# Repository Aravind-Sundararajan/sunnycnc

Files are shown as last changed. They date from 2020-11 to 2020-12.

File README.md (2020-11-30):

# sunnycnc
I was making my own cnc that runs off circuitpython or pycnc and ROS so I thought I should put the files up here. 

I will update the bom as time goes on, but in the current iteration:

**relevant BOM**
* proxxon micromot 50
* raspberry pi3 b+ -I am not sure if I can do octoprint for CNC but I can try
* arduino mega 2560
* RAMPS shield
* 4 NEMA-17 stepper motors

**Power Delivery**
* 12V rail for the micromot (you do NOT need to buy their proprietary power supply) and for nema 17 steppers on the RAMPS 

some modification to mainline marlin tbd or a python script converter that transforms Grbl to reprap 

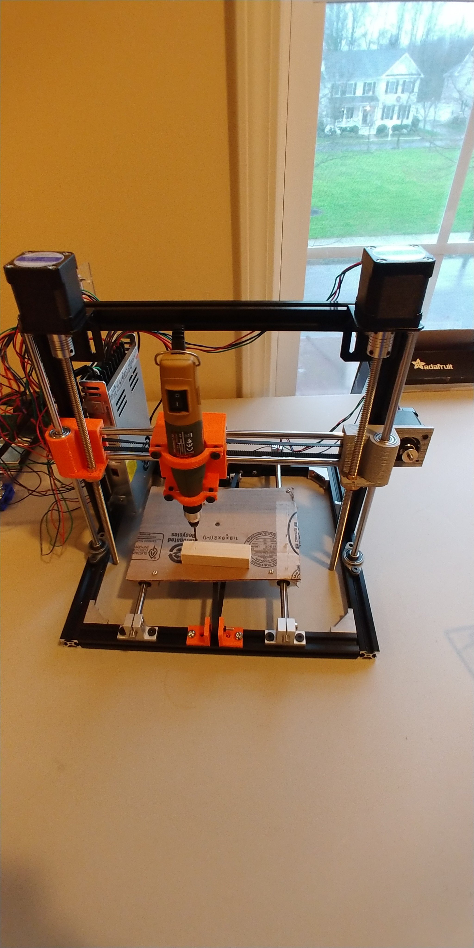
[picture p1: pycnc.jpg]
simple


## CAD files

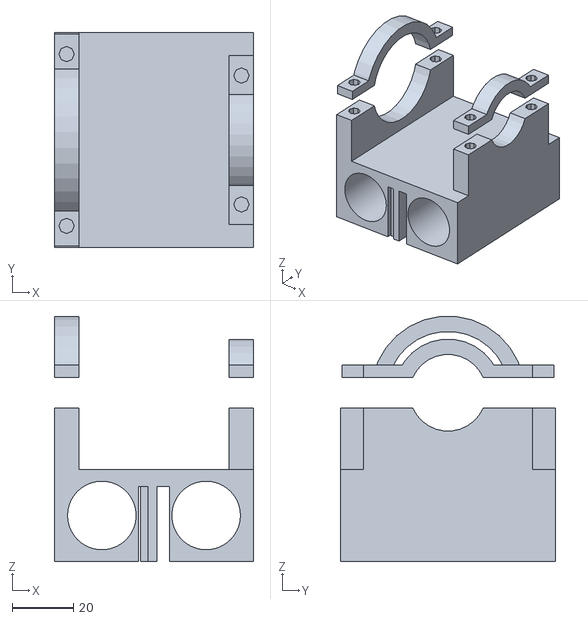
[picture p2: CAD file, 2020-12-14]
stls_and_scad/cnc_holder.stl
65.0 x 70.0 x 79.9

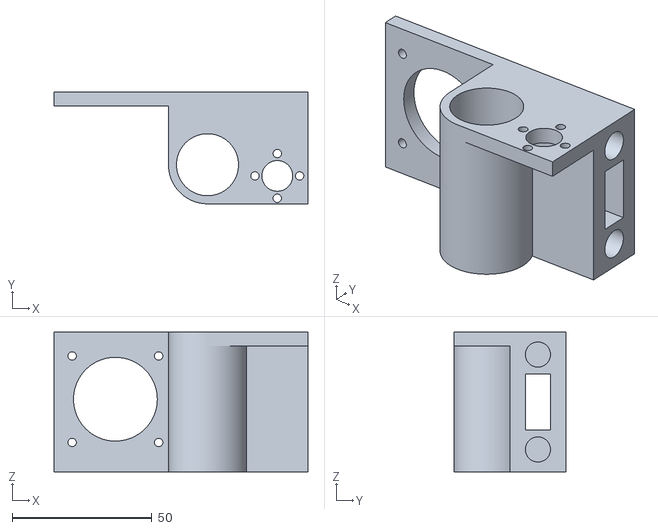
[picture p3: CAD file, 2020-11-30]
stls_and_scad/3d_printer_x_axis_right.stl
91.0 x 40.0 x 50.0

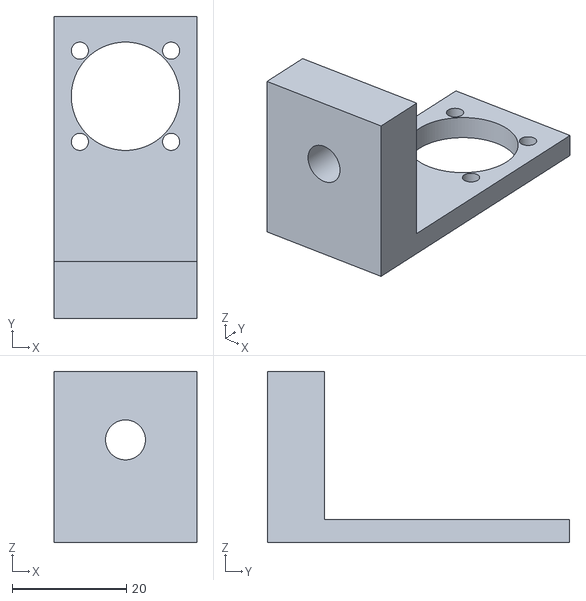
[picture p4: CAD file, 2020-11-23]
stls_and_scad/nema8_holder.stl
25.0 x 53.0 x 30.0

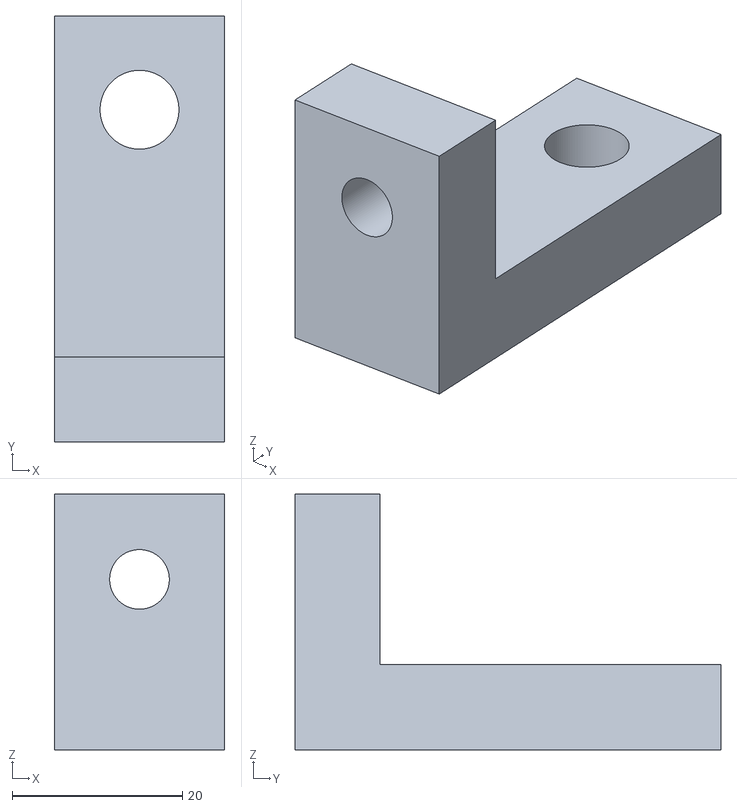
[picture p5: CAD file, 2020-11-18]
stls_and_scad/bar_holder.stl
20.0 x 50.0 x 30.0

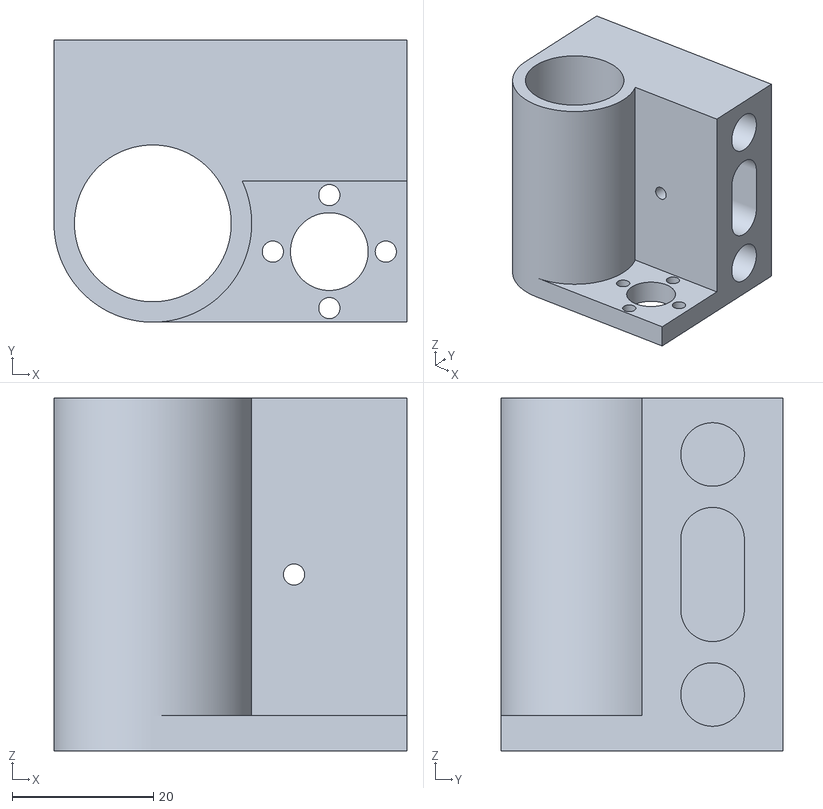
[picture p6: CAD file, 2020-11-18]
stls_and_scad/3d_printer_x_axis_left.stl
50.0 x 40.0 x 50.0

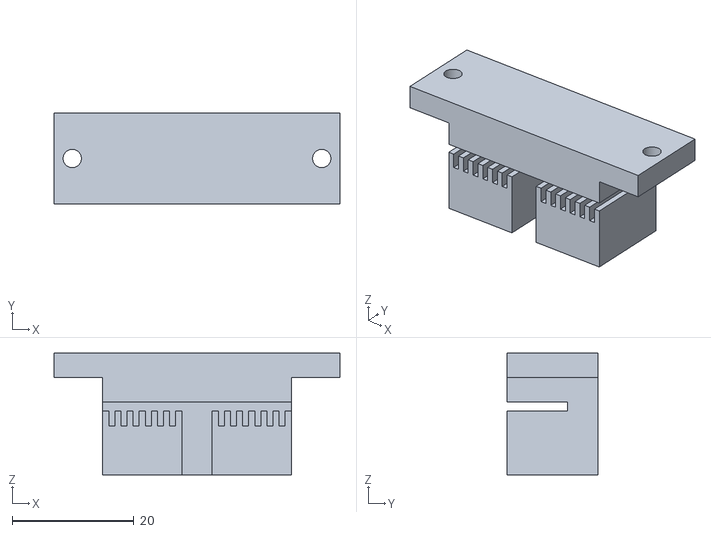
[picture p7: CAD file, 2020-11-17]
stls_and_scad/gantry_g2holder.stl
47.0 x 15.0 x 20.0

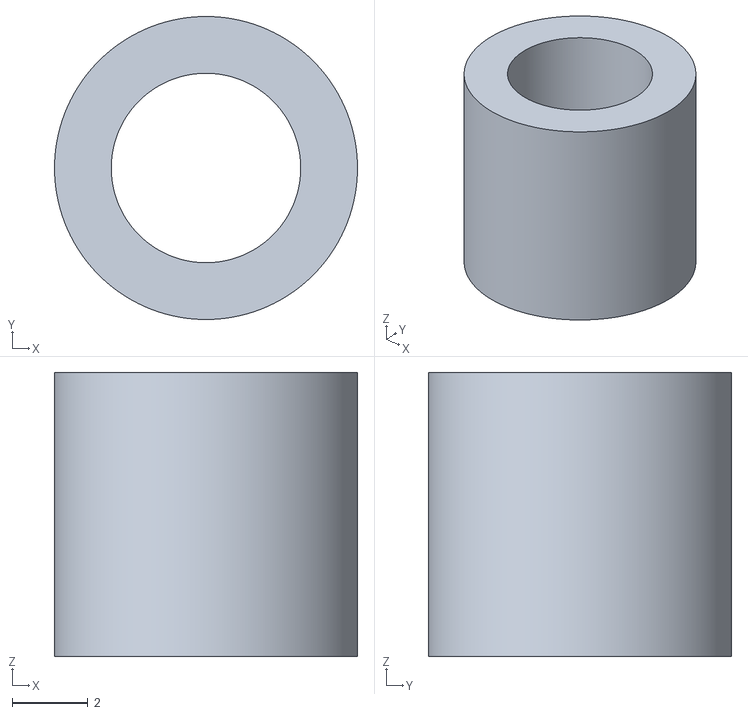
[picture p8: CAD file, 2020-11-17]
stls_and_scad/bearing.stl
8.00 x 8.00 x 7.50

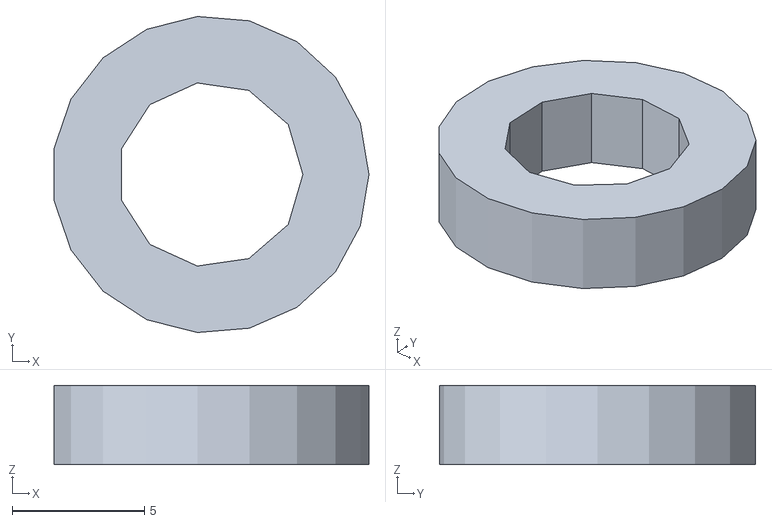
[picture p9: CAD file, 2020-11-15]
stls_and_scad/washer.stl
11.9 x 12.0 x 3.00

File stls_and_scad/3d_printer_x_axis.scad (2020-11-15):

difference(){
    
union(){
translate([10,-10,0]){
cylinder(45,r=10,$fn = 360);
}
translate([0,-10,0]){
cube([20,20,45]);
}
cube([40,10,45]);
translate([10,-20,0]){
cube([30,20,5]);
}
}

//vertical bar hole
translate([10,-10,20]){
cylinder(70,d=9,center=true,$fn = 360);
}


//horizontal bar holes
translate([10,5,40]){
rotate([0,90,0]){
cylinder(70,d=9,$fn = 360);
}
}

translate([10,5,10]){
rotate([0,90,0]){
cylinder(70,d=9,$fn = 360);
}
}

//horizontal slot
union(){
translate([10,5,30]){
rotate([0,90,0]){
cylinder(70,d=9,$fn = 360);
}
}

translate([10,5,20]){
rotate([0,90,0]){
cylinder(70,d=9,$fn = 360);
}
}

translate([45,5,25]){
cube([70,9,10],center=true,$fn = 360);
}
}

translate([30,45,25]){
rotate([90,0,0]){
cylinder(70,d=3,$fn = 360);
}
}




//screw holes

translate([30,-10,30]){
cylinder(140,d=11,center=true,$fn = 360);
}

t = 1 +5.5 + 1.5;
translate([30,-10 +t,30]){
cylinder(70,d=3,$fn = 360,center=true);
}
translate([30,-10 -t,30]){
cylinder(70,d=3,$fn = 360,center=true);
}
translate([30+t,-10 ,30]){
cylinder(70,d=3,$fn = 360,center=true);
}
translate([30-t,-10 ,30]){
cylinder(70,d=3,$fn = 360,center=true);
}



}

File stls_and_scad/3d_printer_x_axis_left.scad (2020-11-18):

/*
	This is the left-side 8mm linear rod holder for the x-axis gantry.
*/
difference(){
    
union(){
translate([10,-10,0]){
cylinder(50,r=14,$fn = 360);
}
translate([-4,-10,0]){
cube([25,20,50]);
}
translate([-4,-4,0]){
cube([50,20,50]);
}
translate([10,-24,0]){
cube([36,20,5]);
}
}

//vertical bar hole
translate([10,-10,20]){
cylinder(70,d=22.2,center=true,$fn = 360);
}


//horizontal bar holes
translate([20,6,42]){
rotate([0,90,0]){
cylinder(50,d=9,$fn = 360);
}
}

translate([20,6,8]){
rotate([0,90,0]){
cylinder(50,d=9,$fn = 360);
}
}

//horizontal slot
union(){
translate([20,6,30]){
rotate([0,90,0]){
cylinder(50,d=9,$fn = 360);
}
}

translate([20,6,20]){
rotate([0,90,0]){
cylinder(50,d=9,$fn = 360);
}
}

translate([45,6,25]){
cube([50,9,10],center=true,$fn = 360);
}
}

translate([30,46,25]){
rotate([90,0,0]){
cylinder(70,d=3,$fn = 360);
}
}




//screw holes

translate([35,-14,30]){
cylinder(140,d=11,center=true,$fn = 360);
}

t = 1 +5.5 + 1.5;
translate([35,-14 +t,30]){
cylinder(70,d=3,$fn = 360,center=true);
}
translate([35,-14 -t,30]){
cylinder(70,d=3,$fn = 360,center=true);
}
translate([35+t,-14 ,30]){
cylinder(70,d=3,$fn = 360,center=true);
}
translate([35-t,-14 ,30]){
cylinder(70,d=3,$fn = 360,center=true);
}



}
//bearing example
//translate([11,0,50]){
//cylinder(7.3,d=22,$fn = 360,center=true);
//}

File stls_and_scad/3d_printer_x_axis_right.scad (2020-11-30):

/*
	This is the right-side 8mm linear rod holder for the x-axis gantry. It also hold one NEMA 8.
*/
difference(){
    
union(){
translate([10,-10,0]){
cylinder(50,r=14,$fn = 360);
}
translate([-45,-10,0]){
cube([60,26,50]);
}
translate([-4,-4,0]){
cube([50,20,50]);
}
translate([10,-24,45]){
cube([36,25,5]);
}

translate([-10,0,20]){
cube([20,18,20],center=true,$fn = 360);
}
translate([-30,3,0]){
//cube([25,20,50]);
}
}

//vertical bar hole
translate([10,-10,20]){
cylinder(70,d=22.2,center=true,$fn = 360);
}


//horizontal bar holes
translate([35,6,42]){
rotate([0,90,0]){
cylinder(50,d=9,$fn = 360);
}
}

translate([35,6,8]){
rotate([0,90,0]){
cylinder(50,d=9,$fn = 360);
}
}

//horizontal slot
translate([-12,6,25]){
cube([120,9,20],center=true,$fn = 360);
}


translate([-23,48,26]){
rotate([90,0,0]){
cylinder(70,d=30,$fn = 360);
}
}

translate([-23+15.5,48,26+15.5]){
rotate([90,0,0]){
cylinder(70,d=3,$fn = 360);
}
}

translate([-23-15.5,48,26+15.5]){
rotate([90,0,0]){
cylinder(70,d=3,$fn = 360);
}
}

translate([-23+15.5,48,26-15.5]){
rotate([90,0,0]){
cylinder(70,d=3,$fn = 360);
}
}

translate([-23-15.5,48,26-15.5]){
rotate([90,0,0]){
cylinder(70,d=3,$fn = 360);
}
}

translate([-26,-6,25]){
cube([44,34,51],center=true,$fn = 360);
}


//screw holes

translate([35,-14,30]){
cylinder(140,d=11,center=true,$fn = 360);
}

t = 1 +5.5 + 1.5;
translate([35,-14 +t,30]){
cylinder(70,d=3,$fn = 360,center=true);
}
translate([35,-14 -t,30]){
cylinder(70,d=3,$fn = 360,center=true);
}
translate([35+t,-14 ,30]){
cylinder(70,d=3,$fn = 360,center=true);
}
translate([35-t,-14 ,30]){
cylinder(70,d=3,$fn = 360,center=true);
}




}

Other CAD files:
stls_and_scad/bar_holder.scad
stls_and_scad/bearing.scad
stls_and_scad/cnc_holder.scad
stls_and_scad/gantry_g2holder.scad
stls_and_scad/nema8_holder.scad
stls_and_scad/washer.scad

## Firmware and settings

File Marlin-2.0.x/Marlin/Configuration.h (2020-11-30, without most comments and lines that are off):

#pragma once
#define CONFIGURATION_H_VERSION 020007
#define STRING_CONFIG_H_AUTHOR "(none, default config)" // Who made the changes.
#define SHOW_BOOTSCREEN
#define SERIAL_PORT 0
#define BAUDRATE 250000
  #define MOTHERBOARD BOARD_RAMPS_14_EFB
#define EXTRUDERS 0
#define DEFAULT_NOMINAL_FILAMENT_DIA 1.75
#define TEMP_SENSOR_0 0
#define TEMP_SENSOR_1 0
#define TEMP_SENSOR_2 0
#define TEMP_SENSOR_3 0
#define TEMP_SENSOR_4 0
#define TEMP_SENSOR_5 0
#define TEMP_SENSOR_6 0
#define TEMP_SENSOR_7 0
#define TEMP_SENSOR_BED 0
#define TEMP_SENSOR_PROBE 0
#define TEMP_SENSOR_CHAMBER 0
#define DUMMY_THERMISTOR_998_VALUE 25
#define DUMMY_THERMISTOR_999_VALUE 100
#define MAX_REDUNDANT_TEMP_SENSOR_DIFF 10
#define TEMP_RESIDENCY_TIME     10  // (seconds) Time to wait for hotend to "settle" in M109
#define TEMP_WINDOW              1  // (°C) Temperature proximity for the "temperature reached" timer
#define TEMP_HYSTERESIS          3  // (°C) Temperature proximity considered "close enough" to the target
#define TEMP_BED_RESIDENCY_TIME 10  // (seconds) Time to wait for bed to "settle" in M190
#define TEMP_BED_WINDOW          1  // (°C) Temperature proximity for the "temperature reached" timer
#define TEMP_BED_HYSTERESIS      3  // (°C) Temperature proximity considered "close enough" to the target
#define HEATER_0_MINTEMP   5
#define HEATER_1_MINTEMP   5
#define HEATER_2_MINTEMP   5
#define HEATER_3_MINTEMP   5
#define HEATER_4_MINTEMP   5
#define HEATER_5_MINTEMP   5
#define HEATER_6_MINTEMP   5
#define HEATER_7_MINTEMP   5
#define BED_MINTEMP        5
#define HEATER_0_MAXTEMP 275
#define HEATER_1_MAXTEMP 275
#define HEATER_2_MAXTEMP 275
#define HEATER_3_MAXTEMP 275
#define HEATER_4_MAXTEMP 275
#define HEATER_5_MAXTEMP 275
#define HEATER_6_MAXTEMP 275
#define HEATER_7_MAXTEMP 275
#define BED_MAXTEMP      150
#define PIDTEMP
#define BANG_MAX 255     // Limits current to nozzle while in bang-bang mode; 255=full current
#define PID_MAX BANG_MAX // Limits current to nozzle while PID is active (see PID_FUNCTIONAL_RANGE below); 255=full current
#define PID_K1 0.95      // Smoothing factor within any PID loop
    #define DEFAULT_Kp  22.20
    #define DEFAULT_Ki   1.08
    #define DEFAULT_Kd 114.00
#define MAX_BED_POWER 255 // limits duty cycle to bed; 255=full current
  #define PID_FUNCTIONAL_RANGE 10 // If the temperature difference between the target temperature and the actual temperature
#define PREVENT_COLD_EXTRUSION
#define EXTRUDE_MINTEMP 170
#define PREVENT_LENGTHY_EXTRUDE
#define EXTRUDE_MAXLENGTH 200
#define THERMAL_PROTECTION_HOTENDS // Enable thermal protection for all extruders
#define THERMAL_PROTECTION_BED     // Enable thermal protection for the heated bed
#define THERMAL_PROTECTION_CHAMBER // Enable thermal protection for the heated chamber
#define USE_XMIN_PLUG
#define USE_YMIN_PLUG
#define USE_ZMIN_PLUG
#define USE_XMAX_PLUG
#define USE_YMAX_PLUG
#define USE_ZMAX_PLUG
#define ENDSTOPPULLUPS
#define X_MIN_ENDSTOP_INVERTING true // Set to true to invert the logic of the endstop.
#define Y_MIN_ENDSTOP_INVERTING true // Set to true to invert the logic of the endstop.
#define Z_MIN_ENDSTOP_INVERTING true // Set to true to invert the logic of the endstop.
#define X_MAX_ENDSTOP_INVERTING true // Set to true to invert the logic of the endstop.
#define Y_MAX_ENDSTOP_INVERTING true // Set to true to invert the logic of the endstop.
#define Z_MAX_ENDSTOP_INVERTING true // Set to true to invert the logic of the endstop.
#define Z_MIN_PROBE_ENDSTOP_INVERTING true // Set to true to invert the logic of the probe.
#define DEFAULT_AXIS_STEPS_PER_UNIT   { 80, 80, 4000, 500 }
#define DEFAULT_MAX_FEEDRATE          { 300, 300, 5, 25 }
#define DEFAULT_MAX_ACCELERATION      { 3000, 3000, 100, 10000 }
#define DEFAULT_ACCELERATION          3000    // X, Y, Z and E acceleration for printing moves
#define DEFAULT_RETRACT_ACCELERATION  3000    // E acceleration for retracts
#define DEFAULT_TRAVEL_ACCELERATION   3000    // X, Y, Z acceleration for travel (non printing) moves
#define DEFAULT_EJERK    5.0  // May be used by Linear Advance
  #define JUNCTION_DEVIATION_MM 0.013 // (mm) Distance from real junction edge
  #define JD_HANDLE_SMALL_SEGMENTS    // Use curvature estimation instead of just the junction angle
#define Z_MIN_PROBE_USES_Z_MIN_ENDSTOP_PIN
#define NOZZLE_TO_PROBE_OFFSET { 10, 10, 0 }
#define PROBING_MARGIN 10
#define XY_PROBE_SPEED (133*60)
#define Z_PROBE_SPEED_FAST HOMING_FEEDRATE_Z
#define Z_PROBE_SPEED_SLOW (Z_PROBE_SPEED_FAST / 2)
#define Z_CLEARANCE_DEPLOY_PROBE   10 // Z Clearance for Deploy/Stow
#define Z_CLEARANCE_BETWEEN_PROBES  5 // Z Clearance between probe points
#define Z_CLEARANCE_MULTI_PROBE     5 // Z Clearance between multiple probes
#define Z_PROBE_LOW_POINT          -2 // Farthest distance below the trigger-point to go before stopping
#define Z_PROBE_OFFSET_RANGE_MIN -20
#define Z_PROBE_OFFSET_RANGE_MAX 20
#define X_ENABLE_ON 0
#define Y_ENABLE_ON 0
#define Z_ENABLE_ON 0
#define E_ENABLE_ON 0 // For all extruders
#define DISABLE_X false
#define DISABLE_Y false
#define DISABLE_Z false
#define DISABLE_E false             // Disable the extruder when not stepping
#define DISABLE_INACTIVE_EXTRUDER   // Keep only the active extruder enabled
#define INVERT_X_DIR false
#define INVERT_Y_DIR true
#define INVERT_Z_DIR false
#define INVERT_E0_DIR false
#define INVERT_E1_DIR false
#define INVERT_E2_DIR false
#define INVERT_E3_DIR false
#define INVERT_E4_DIR false
#define INVERT_E5_DIR false
#define INVERT_E6_DIR false
#define INVERT_E7_DIR false
#define X_HOME_DIR 1
#define Y_HOME_DIR 1
#define Z_HOME_DIR 1
#define X_BED_SIZE 200
#define Y_BED_SIZE 200
#define X_MIN_POS 0
#define Y_MIN_POS 0
#define Z_MIN_POS 0
#define X_MAX_POS X_BED_SIZE
#define Y_MAX_POS Y_BED_SIZE
#define Z_MAX_POS 200
#define MIN_SOFTWARE_ENDSTOPS
  #define MIN_SOFTWARE_ENDSTOP_X
  #define MIN_SOFTWARE_ENDSTOP_Y
  #define MIN_SOFTWARE_ENDSTOP_Z
#define MAX_SOFTWARE_ENDSTOPS
  #define MAX_SOFTWARE_ENDSTOP_X
  #define MAX_SOFTWARE_ENDSTOP_Y
  #define MAX_SOFTWARE_ENDSTOP_Z
#define HOMING_FEEDRATE_XY (1000)
#define HOMING_FEEDRATE_Z  (20)
#define VALIDATE_HOMING_ENDSTOPS
#define EEPROM_CHITCHAT       // Give feedback on EEPROM commands. Disable to save PROGMEM.
#define EEPROM_BOOT_SILENT    // Keep M503 quiet and only give errors during first load
#define HOST_KEEPALIVE_FEATURE        // Disable this if your host doesn't like keepalive messages
#define DEFAULT_KEEPALIVE_INTERVAL 2  // Number of seconds between "busy" messages. Set with M113.
#define BUSY_WHILE_HEATING            // Some hosts require "busy" messages even during heating
#define PREHEAT_1_LABEL       "PLA"
#define PREHEAT_1_TEMP_HOTEND 180
#define PREHEAT_1_TEMP_BED     70
#define PREHEAT_1_FAN_SPEED     0 // Value from 0 to 255
#define PREHEAT_2_LABEL       "ABS"
#define PREHEAT_2_TEMP_HOTEND 240
#define PREHEAT_2_TEMP_BED    110
#define PREHEAT_2_FAN_SPEED     0 // Value from 0 to 255
#define PRINTJOB_TIMER_AUTOSTART
#define LCD_LANGUAGE en
#define DISPLAY_CHARSET_HD44780 JAPANESE
#define LCD_INFO_SCREEN_STYLE 0
#define SOFT_PWM_SCALE 0
#define SERVO_DELAY { 300 }

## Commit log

2020-11-17 developing several adapters for the bar and gantry. X-axis assembly is not steady, modification required (perhaps actual bearings)
    [bar_holder.scad, bar_holder.stl, bearing.scad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]
2020-11-17 reorganized folder, added image
    [3d_printer_x_axis.scad, 3d_printer_x_axis.stl, 3d_printer_x_axis_right.scad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]
2020-11-17 added comments for the scads
    [3d_printer_x_axis_left.scad, 3d_printer_x_axis_left.stl, 3d_printer_x_axis_right.scad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]
2020-11-18 modified the x-axis gantry to be sturdier and replaced the vertical slots with larger diameter that allows for 22mm bearings like 684zz. Smooth linear in Z. similar modification to be done to the dre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
    [3d_printer_x_axis_left.scad, 3d_printer_x_axis_left.stl, 3d_printer_x_axis_right.scad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]
2020-11-18 resized the nema and linear rod holders
    [bar_holder.scad, bar_holder.stl, nema8_holder.scad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]
2020-11-20 modified the cnc holder to support 22mm bearings
    [cnc_holder.scad, cnc_holder.stl]
2020-11-23 NEMA 8 don't deliver enough torque to drive the carriage Y and X
    [cnc_holder.scad, cnc_holder.stl, nema8_holder.scad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]
2020-11-30 No more circuitpython, switched to mainline marlin
    [3d_printer_x_axis_right.scad, 3d_printer_x_axis_right.stl, Configuration.h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]
2020-12-14 modified the cnc holder for 4 bearings, fine-tuning feedrates in marlin, have to invert the axis directions (engraving came out mirrored)
    [cnc_holder.scad, cnc_holder.stl]

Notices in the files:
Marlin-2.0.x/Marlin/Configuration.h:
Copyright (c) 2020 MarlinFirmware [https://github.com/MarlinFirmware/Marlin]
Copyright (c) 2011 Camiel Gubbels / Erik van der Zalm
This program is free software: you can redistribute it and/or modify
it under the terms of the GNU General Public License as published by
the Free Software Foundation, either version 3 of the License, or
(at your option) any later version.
